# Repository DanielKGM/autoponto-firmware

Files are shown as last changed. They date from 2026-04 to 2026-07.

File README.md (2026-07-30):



[][doi-url]
[][contributors-url]
[][forks-url]
[][stars-url]
[][issues-url]
[][linkedin-url]

<!-- PROJECT LOGO -->
<br />
<div align="center">
  <a href="https://github.com/DanielKGM/autoponto-firmware">
    
  </a>

<h3 align="center">Chamadas Acadêmicas por Reconhecimento Facial</h3><br />
  <p align="center">
    <strong>AutoPonto</strong> é um sistema distribuído de computação de borda composto por três repositórios: código de <i>firmware</i>, aplicação <i>web</i> e servidor de borda. O objetivo é criar uma solução <b>barata</b> e <b>escalável</b> para automatização de chamadas acadêmicas através do reconhecimento facial, utilizando camadas independentes e conectadas por uma rede local. 
    <br /><br />
    <u>Este repositório</u> guarda o código-fonte do <i>firmware</i> dos dispositivos embarcados que são posicionados em salas de aula, responsáveis por coletar dados e interagir com usuários.
    <br />
    <br />
    <a href="https://github.com/DanielKGM/autoponto">Servidor Principal</a>
    &middot;
    <a href="https://github.com/DanielKGM/autoponto-edgenode">AutoPonto <i>EdgeNode</i></a>
    &middot;
    <a href="https://github.com/DanielKGM/autoponto-firmware/issues/new?labels=bug&template=bug-report---.md">Reportar Erro</a>
    &middot;
    <a href="https://github.com/DanielKGM/autoponto-firmware/issues/new?labels=enhancement&template=feature-request---.md">Sugerir Algo</a>
  </p>
</div>

<!-- TABLE OF CONTENTS -->
<details>
  <summary>Sumário</summary>
  <ol>
    <li><a href="#arquitetura-geral">Arquitetura Geral</a></li>
    <li><a href="#lista-de-materiais">Lista de Materiais</a></li>
    <li><a href="#esquema-elétrico-do-dispositivo">Esquema Elétrico do Dispositivo</a></li>
    <li><a href="#objetivos-específicos">Objetivos Específicos</a></li>
    <li><a href="#fluxo-de-execução">Fluxo de Execução</a></li>
    <li><a href="#estados-do-dispositivo">Estados do Dispositivo</a></li>
    <li><a href="#dependências-do-firmware">Dependências do <i>Firmware</i></a></li>
    <li><a href="#placa-de-circuito-impresso">Placa de Circuito Impresso</a></li>
    <li><a href="#caixa-de-montagem">Caixa de Montagem</a></li>
    <li><a href="#fotos-em-funcionamento">Fotos em Funcionamento</a></li>
    <li><a href="#configuração-local">Configuração Local</a></li>
    <li><a href="#mapa-de-arquivos">Mapa de Arquivos</a></li>
    <li><a href="#contexto-de-aula">Contexto de Aula</a></li>
    <li>
      <a href="#contrato-rest">Contrato <i>REST</i></a>
      <ul>
        <li><a href="#buscar-contexto">Buscar Contexto</a></li>
        <li><a href="#enviar-frame">Enviar <i>Frame</i></a></li>
      </ul>
    </li>
    <li>
      <a href="#contrato-mqtt">Contrato <i>MQTT</i></a>
      <ul>
        <li><a href="#status"><i>Status</i></a></li>
        <li><a href="#métricas">Métricas</a></li>
      </ul>
    </li>
    <li><a href="#contato">Contato</a></li>
    <li><a href="#licença-e-citação">Licença e Citação</a></li>
    <li><a href="#agradecimentos">Agradecimentos</a></li>
  </ol>
</details>

## Arquitetura Geral

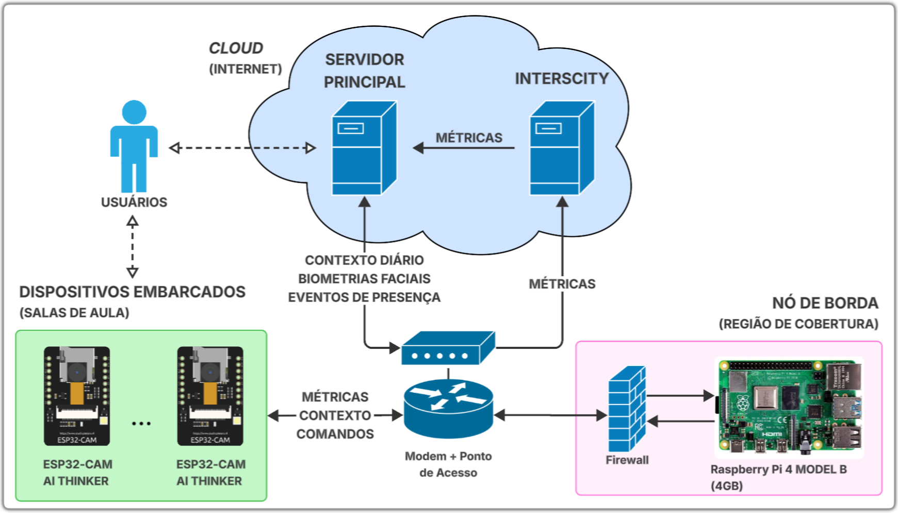
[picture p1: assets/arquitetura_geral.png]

<p align="justify">Quanta coisa é preciso para automatizar chamadas acadêmicas? Por exemplo, informações sobre o curso e rostos de alunos precisam ser cadastrados; então, em sala de aula, fotos precisam ser capturadas e capturas precisam ser processadas. Para atingir esses e (muitos) outros objetivos, o projeto utiliza uma arquitetura distribuída chamada <a href="https://www.intel.com/content/www/us/en/learn/what-is-edge-computing.html">computação de borda</a>. Isso permite diluir um monte de funcionalidades em camadas independentes, mas cooperativas:</p>
<ul>
<li><b>Dispositivos Embarcados</b> (este repositório): dispositivos eletrônicos posicionados em salas de aula. Eles são responsáveis por capturar fotos e exibir mensagens, portanto, interagem frequente e diretamente com os usuários;</li>
<li><b><a href="https://github.com/DanielKGM/autoponto-edgenode">Nó de Borda</a></b>: servidor intermediário implementado em <i>Raspberry Pi 4</i> ou outros <i>Single Board Computer</i> (<i>SBC</i>), seu propósito é fazer o reconhecimento facial, conectar os dispositivos embarcados com o servidor principal e armazenar uma parte <b>relevante</b> dos dados a cada sincronização (como rostos, aulas, alunos, matrículas, etc.);</li>
<li><b><a href="https://github.com/DanielKGM/autoponto">Servidor Principal</a></b>: regras de negócio, gerenciamento de usuários, persistência de dados, coleta biométrica, interface <i>web</i>, <i>dashboards</i>, relatórios, formulários <i>CRUD</i>, sincronização com nós, mapa <i>IoT</i>.</li>
<li><b><a href="https://github.com/DanielKGM/Playground_InterSCity">InterSCity</a></b> (opcional): trata-se de um <i>middleware IoT</i> feito por pesquisadores brasileiros da USP, onde métricas e <i>status</i> dos dispositivos podem ser publicados (pelos nós) e lidos (por aplicações). Não é necessário para o funcionamento do projeto, mas altamente recomendado como camada de <u>telemetria e monitoramento</u>.</li>
</ul>
<br/>
<p align="right">(<a href="#topo">voltar ao topo</a>)</p>

## Lista de Materiais

| Imagem | Componente <i>THT</i> | Especificação | Quantidade |
| :---: | :--- | :--- | :---: |
|  Fonte SAMSUNG | [Fonte de alimentação](<[URL_ALIEXPRESS_AQUI](https://www.mercadolivre.com.br/carregador-samsung-epta50bw-j6-j8-a6-plus-e5-de-15-ampere-fabricado-no-brasil/p/MLB19713348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)>) | Samsung EP-TA50BW, saída 5 Vcc e corrente máxima de 1,55 A | 1 |
| Conversor Bucker | [Conversor de tensão](https://pt.aliexpress.com/item/1005007653423578.html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) | MP1584, conversor <i>buck</i>, saída ajustada para 3,3 V | 1 |
| ESP32-CAM Devboard | [Microcontrolador com câmera](https://www.aliexpress.com/item/1005006967566203.html) | <i>ESP32-CAM</i> AI-Thinker | 1 |
| Display TFT redondo | [Módulo de <i>display</i>](https://pt.aliexpress.com/item/1005009766462228.html) | <i>TFT</i> circular 1,28'', controlador GC9A01, interface <i>SPI</i> | 1 |
| Sensor de presença | [Sensor de presença](https://pt.aliexpress.com/item/32946280844.html) | HC-SR602, sensor <i>PIR</i> de movimento | 1 |
| - | <i>Buzzer</i> ativo | TMB12A03, alimentação nominal de 3 V | 1 |
| - | Transistor <i>NPN</i> | S9013, usado no chaveamento do <i>display</i> e do indicador | 2 |
| - | Diodo <i>Schottky</i> | 1N5819, usado na proteção de alimentação e no circuito do IO4 | 2 |
| - | <i>LED</i> verde | Indicador visual de retorno positivo | 1 |
| - | <i>LED</i> azul | Indicador visual de alimentação | 1 |
| - | Resistor | 220 Ω | 1 |
| - | Resistor | 1 kΩ | 3 |
| - | Resistor | 4,7 kΩ | 1 |
| - | Resistor | 10 kΩ | 2 |
| - | Resistor | 20 kΩ | 1 |
| - | Capacitor cerâmico | 100 nF | 3 |
| - | Capacitor eletrolítico | 220 μF | 1 |
| Borne | Borne de entrada | KF128-MINI, 2 vias | 1 |
| Interruptor | [Interruptor gangorra](https://pt.aliexpress.com/item/1005009248936075.html) | KCD11, liga/desliga da alimentação | 1 |
| - | Chave tátil | 12D00G ou equivalente | 1 |
| - | [Placa de circuito impresso](https://jlcpcb.com/) | <i>PCB</i> do dispositivo embarcado | 5 |

<p align="right">(<a href="#topo">voltar ao topo</a>)</p>

## Esquema Elétrico do Dispositivo

A tabela abaixo separa o esquema elétrico total do dispositivo embarcado em diferentes partes, de acordo com a função de cada uma. Na prática, todas funcionam em conjunto em uma única placa de circuito impresso (<i>PCB</i>).

| Esquema Elétrico | Função no Dispositivo |
| :---: | :--- |
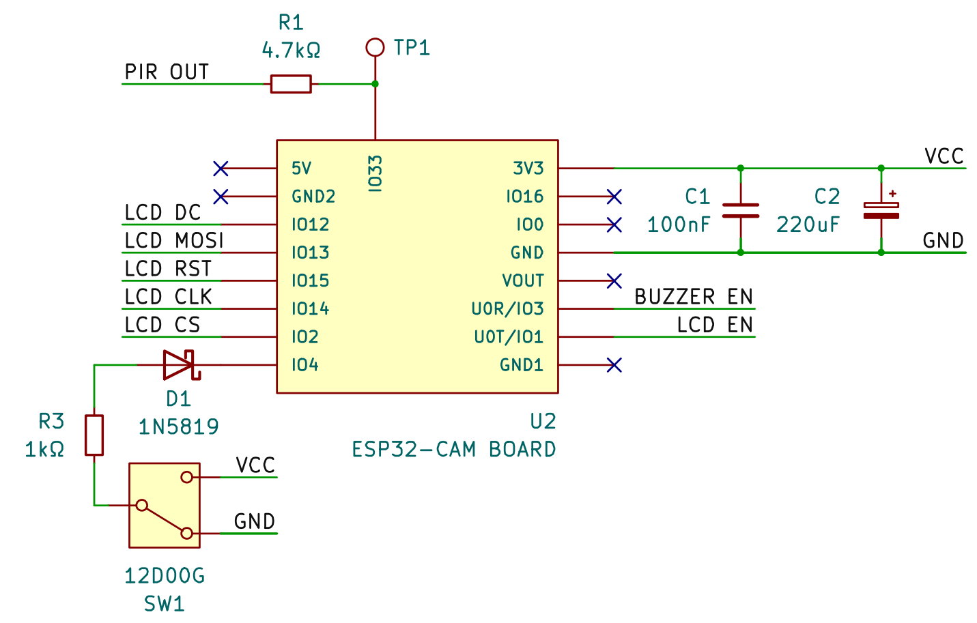
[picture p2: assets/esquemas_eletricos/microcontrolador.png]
Microcontrolador
| <br><sub>Microcontrolador</sub> | Atua como o "cérebro" do dispositivo. É responsável por executar o <i>firmware</i>, processar cálculos lógicos, receber dados dos sensores e enviar comandos para o <i>display</i> e indicadores. |
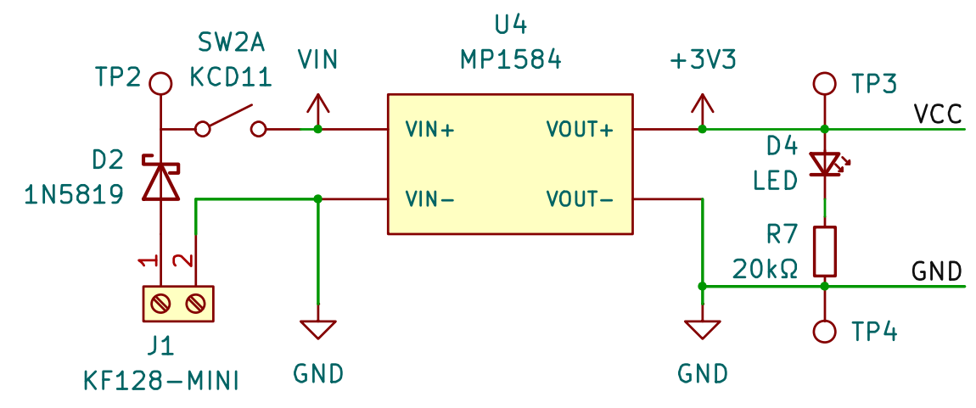
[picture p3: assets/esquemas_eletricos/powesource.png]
Fonte de Alimentação
| <br><sub>Fonte de Alimentação (<i>Power Source</i>)</sub> | Gerencia a energia do sistema. Recebe a energia externa e a converte/regula para 3.3V a fim de alimentar todos os componentes de forma segura e estável. |
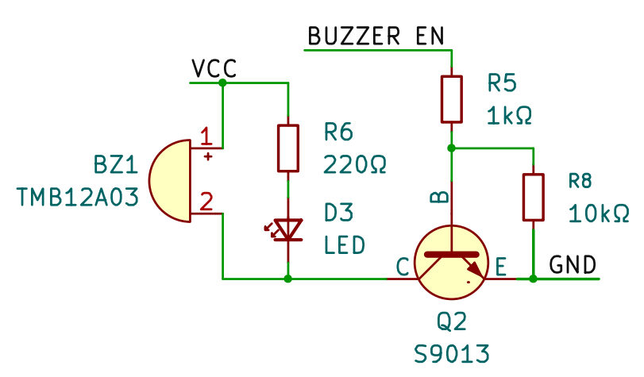
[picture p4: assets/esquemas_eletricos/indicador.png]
Indicador
| <br><sub>Indicador Visual (<i>Status</i>)</sub> | Fornece <i>feedback</i> visual e sonoro simples e rápido sobre o estado operacional do dispositivo. O <i>LED</i> verde é interpretado como um sinal positivo. |
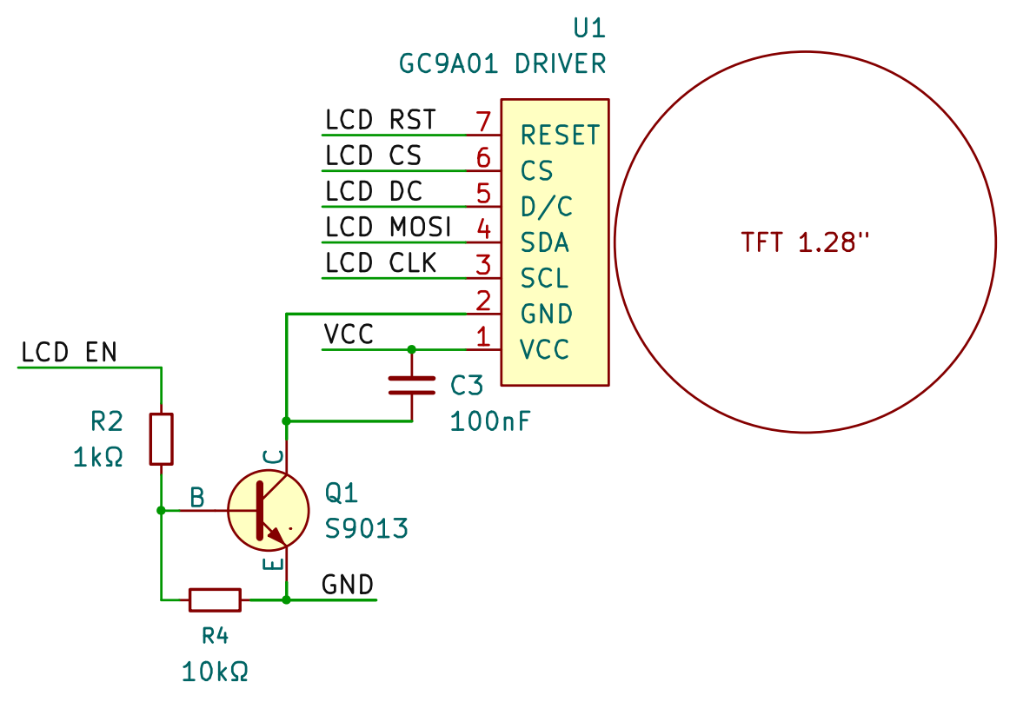
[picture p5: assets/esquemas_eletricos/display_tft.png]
Display TFT
| <br><sub><i>Display TFT</i></sub> | Interface gráfica do sistema. Utilizada para exibir informações mais detalhadas ao usuário e imagens da câmera em tempo real. |
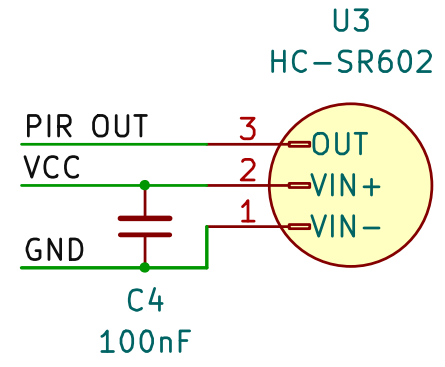
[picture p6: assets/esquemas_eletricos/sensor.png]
Sensor
| <br><sub><i>Sensor</i></sub> | Envia para o microcontrolador um sinal de usuário fisicamente presente/próximo ao dispositivo. Serve para ligá-lo ou retirar do modo de espera. |

<p align="right">(<a href="#topo">voltar ao topo</a>)</p>

## Objetivos Específicos

- Identificar o dispositivo pelo <i>MAC eFuse</i> do <i>ESP32</i>;
- Conectar ao <i>Wi-Fi</i> e ao <i>broker MQTT</i> configurados em <i>build time</i>;
- Buscar no <i>EdgeNode</i> o contexto de aula/chamada atual;
- Exibir <i>preview</i> da câmera ou mensagens de estado no <i>TFT</i>;
- Enviar <i>frames JPEG</i> periodicamente enquanto existe chamada ativa;
- Receber <i>feedback</i> de autenticação pelo <i>MQTT</i>;
- Publicar <i>status</i>, métricas de saúde e eventos de presença;
- Economizar energia quando não há movimento detectado pelo <i>PIR</i>.

<p align="right">(<a href="#topo">voltar ao topo</a>)</p>

## Fluxo de Execução

`src/main.cpp` é o ponto de entrada.

1. Desativa <i>brownout</i>, configura pinos e marca o estado `BOOTING`.
2. Gera `deviceId` a partir do <i>MAC eFuse</i> do <i>ESP32</i>.
3. Inicializa <i>TFT</i>, <i>sprites</i> de desenho, <i>sleep</i> e câmera.
4. Cria tarefas <i>FreeRTOS</i> para <i>display</i>, câmera, rede e <i>MQTT</i>.
5. No `loop()`, expira o contexto de aula, processa <i>PIR</i>, aciona <i>feedback</i> positivo,
   entra/sai de <i>idle</i> e dispara <i>deep sleep</i> quando aplicável.

As tarefas principais rodam em paralelo:

- `TaskDisplay`: desenha mensagens, <i>preview</i> da câmera e informações de contexto.
- `TaskCamera`: captura <i>frames</i> da câmera, alimenta <i>preview</i> e <i>snapshots REST</i>.
- `TaskNetwork`: conecta <i>Wi-Fi</i>, busca contexto <i>REST</i> e envia <i>frames JPEG</i>.
- `TaskMqtt`: conecta ao <i>broker</i>, assina comandos e publica <i>status</i>/métricas.

<p align="right">(<a href="#topo">voltar ao topo</a>)</p>

## Estados do Dispositivo

Os estados ficam em `include/Globals.h`:

- `BOOTING`: inicialização local.
- `NET_OFF`: <i>Wi-Fi</i> desconectado.
- `MQTT_OFF`: <i>Wi-Fi</i> ativo, <i>MQTT</i> desconectado.
- `FETCHING`: precisa buscar contexto de aula no <i>REST</i>.
- `WORKING`: contexto válido e operação normal.
- `WAITING_SERVER`: <i>frame</i> enviado, aguardando retorno pelo <i>MQTT</i> ou <i>timeout</i>.
- `SLEEPING`: preparando <i>deep sleep</i>.

`setState()` em `src/Globals.cpp` também publica <i>status MQTT</i> retido quando o
<i>broker</i> está conectado:

- `working`
- `fetching`
- `sleep`

A figura abaixo ilustra a máquina de estados do dispositivo embarcado:

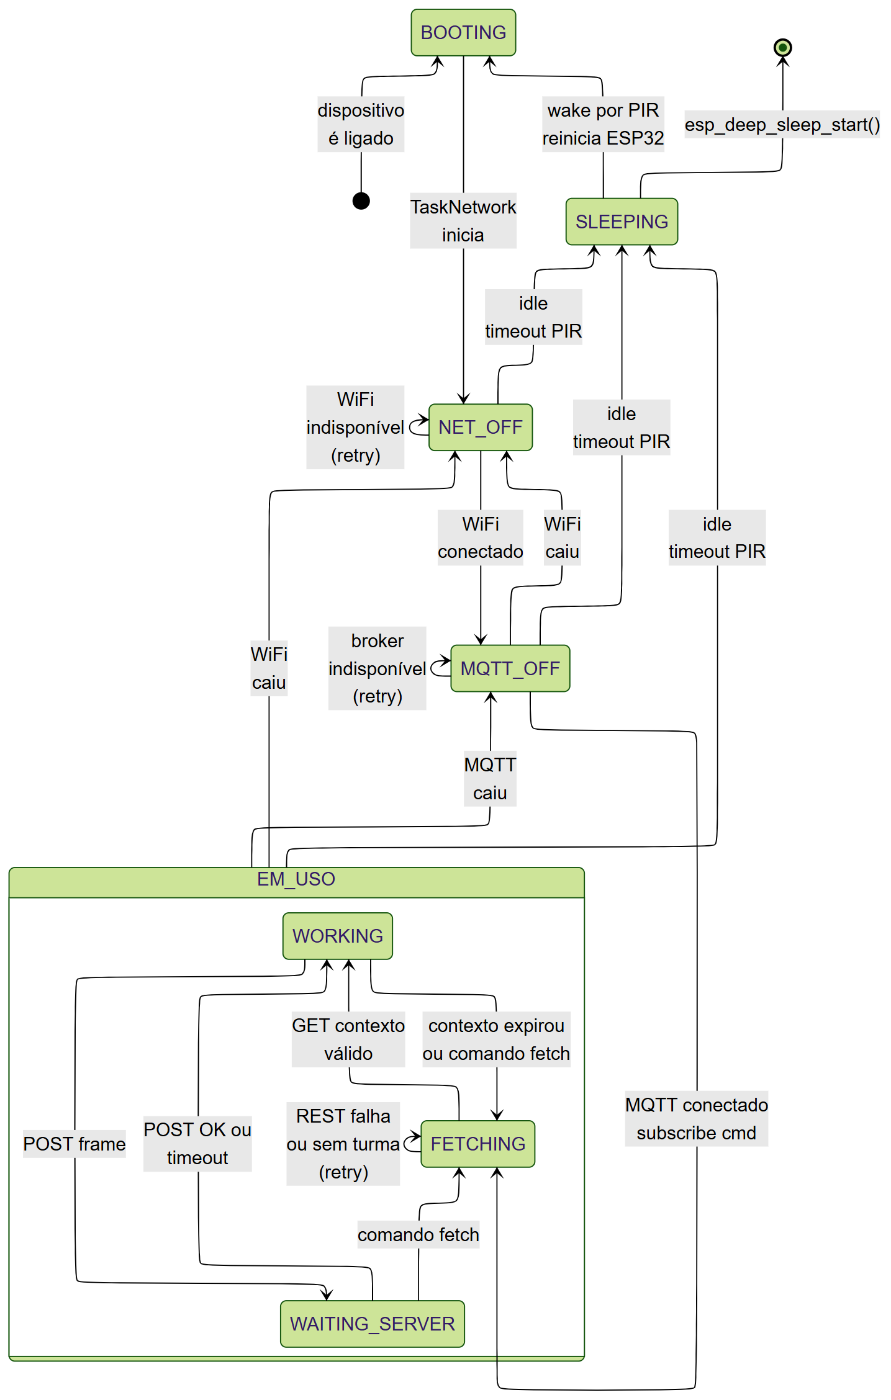
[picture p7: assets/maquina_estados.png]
Máquina de estados


<p align="right">(<a href="#topo">voltar ao topo</a>)</p>

## Dependências do <i>Firmware</i>

- <i>Framework</i>: Arduino sobre <i>ESP32</i> via <i>PlatformIO</i>
- Comunicação: <i>Wi-Fi</i>, <i>HTTP REST</i> e <i>MQTT</i>

| Dependência | Descrição |
| :--- | :--- |
| [bodmer/TFT_eSPI](https://github.com/Bodmer/TFT_eSPI) | Biblioteca gráfica e de fontes altamente otimizada para <i>displays TFT</i> baseados em <i>SPI</i>, focada em microcontroladores como <i>ESP8266</i>, <i>ESP32</i> e <i>RP2040</i>. |
| [bitbank2/JPEGDEC](https://github.com/bitbank2/JPEGDEC) | Decodificador <i>JPEG</i> otimizado para microcontroladores (escrito em C/C++), permitindo carregar e exibir imagens em <i>displays</i> com uso eficiente de memória. |
| [bblanchon/ArduinoJson](https://github.com/bblanchon/ArduinoJson) | Biblioteca de C++ eficiente e poderosa para serialização e desserialização de dados no formato <i>JSON</i>, muito utilizada em projetos Arduino e <i>IoT</i>. |
| [knolleary/PubSubClient](https://github.com/knolleary/pubsubclient) | Biblioteca para Arduino que fornece um cliente para o protocolo <i>MQTT</i> (<i>Message Queuing Telemetry Transport</i>), permitindo publicar e assinar tópicos para comunicação <i>IoT</i> em tempo real. |

<p align="right">(<a href="#topo">voltar ao topo</a>)</p>

## Placa de Circuito Impresso

Os circuitos eletrônicos do dispositivo são desenhados em uma placa de circuito impresso (PCB). Abaixo está o modelo 3D da PCB.

- [Clique neste LINK para visualizar em 3D](https://3dviewer.net/index.html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) &middot; [Arquivo Gerber](https://github.com/DanielKGM/autoponto-firmware/tree/main/assets/pcb)

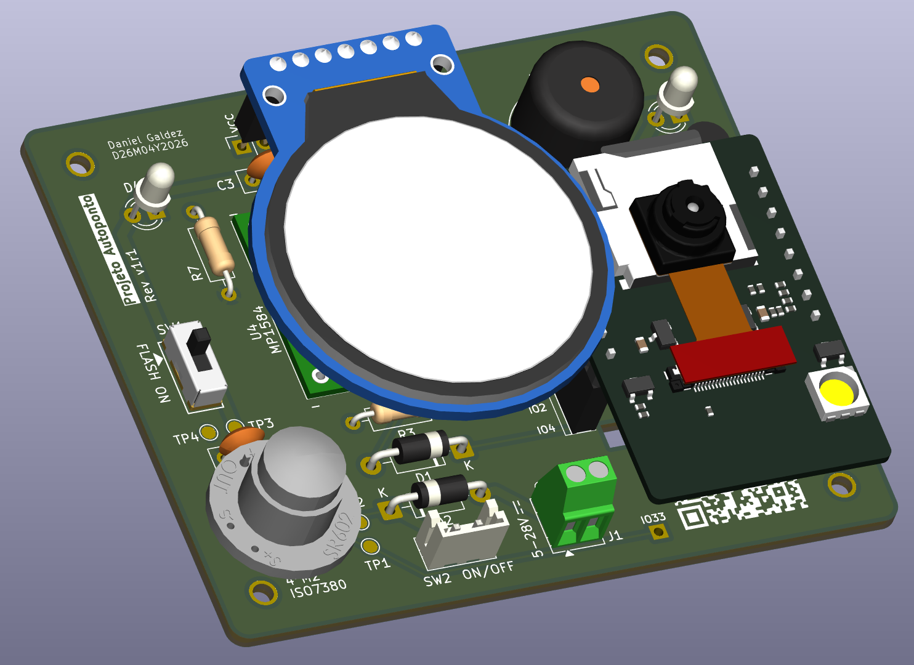
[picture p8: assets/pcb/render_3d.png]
Placa de Circuito Impresso


<p align="right">(<a href="#topo">voltar ao topo</a>)</p>

## Caixa de Montagem

Para testes em campo, os componentes eletrônicos e PCB precisam ser protegidos por uma caixa de montagem. A figura abaixo mostra o modelo 3D da caixa, que pode ser impresso em <i>PLA</i> ou outro material resistente.

- Clique nos LINKS a seguir para visualizar os arquivos de impressão: [BASE](https://3dviewer.net/index.html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) &middot; [TAMPA](https://3dviewer.net/index.html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) &middot; [TAMPA (SEM LOGO)](https://3dviewer.net/index.html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)

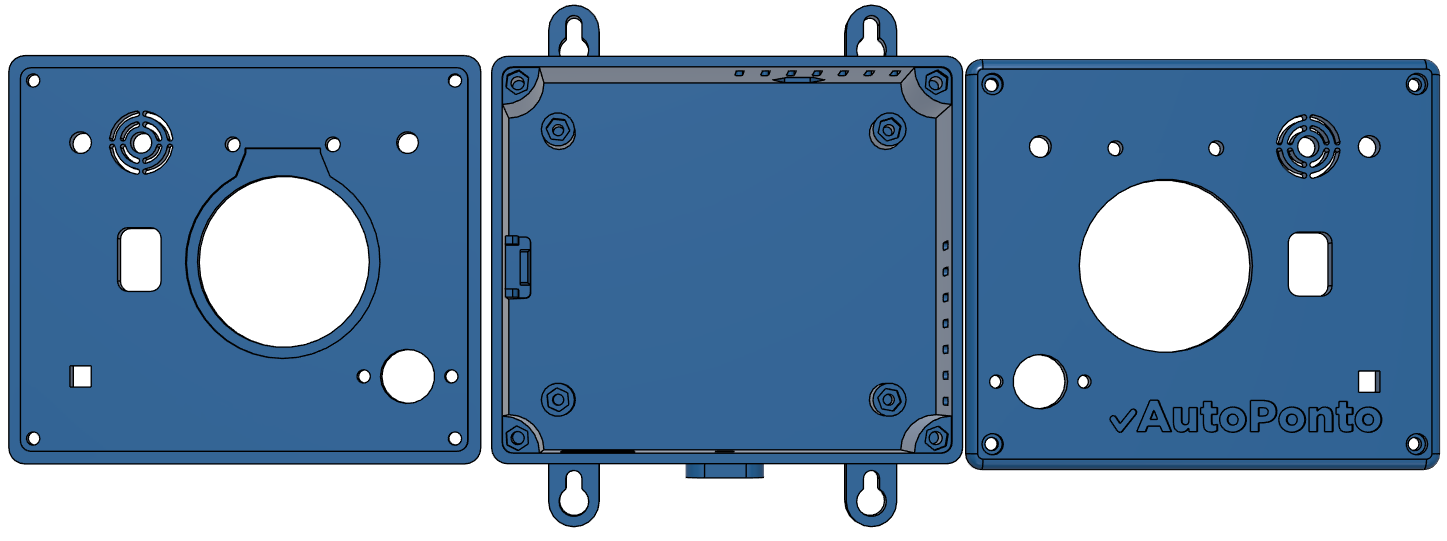
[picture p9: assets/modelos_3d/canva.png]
Caixa de Montagem


<p align="right">(<a href="#topo">voltar ao topo</a>)</p>

## Fotos em Funcionamento

| | |
| :---: | :---: |
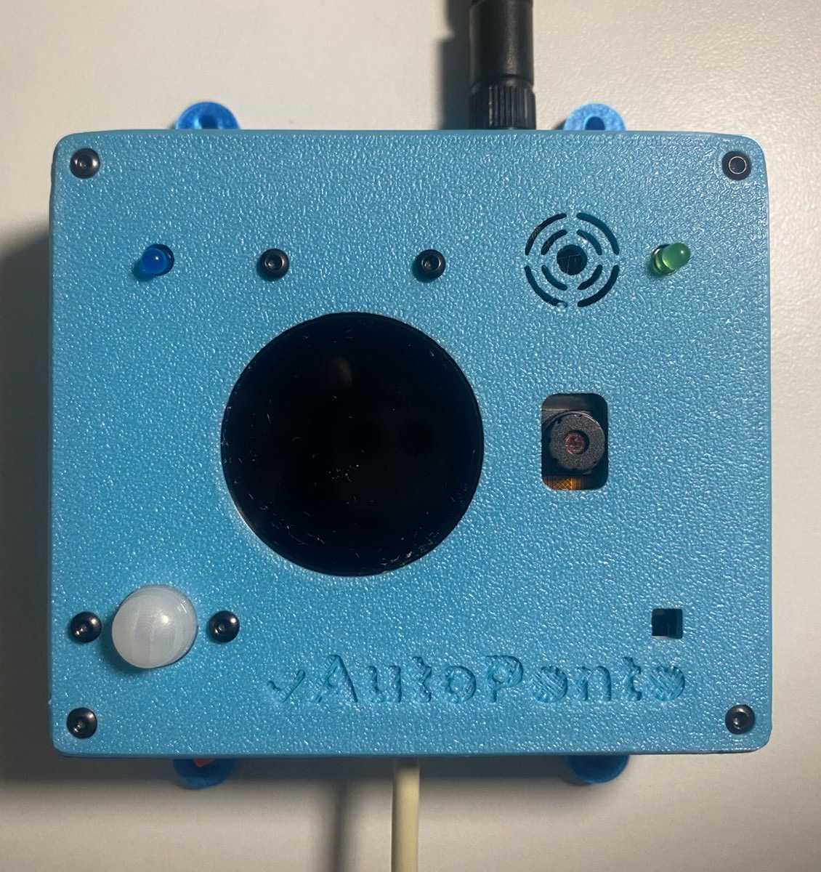
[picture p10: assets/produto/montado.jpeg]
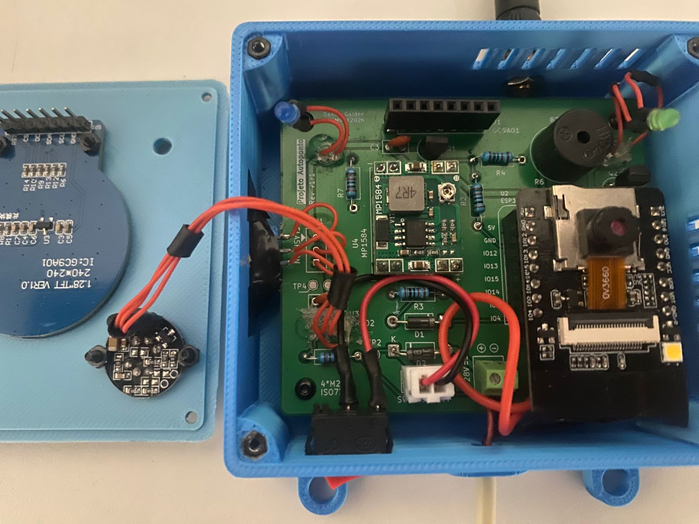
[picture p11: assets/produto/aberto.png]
| <br><sub>Dispositivo montado, não energizado</sub> | <br><sub>Por dentro do dispositivo embarcado</sub> |
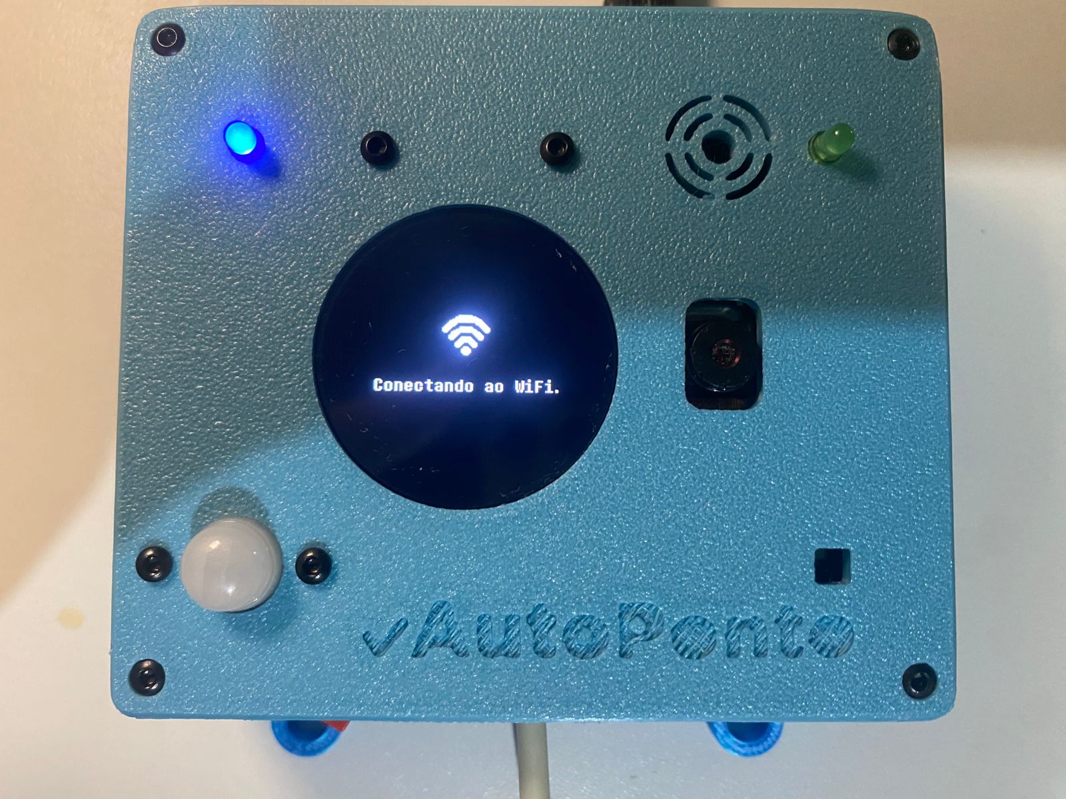
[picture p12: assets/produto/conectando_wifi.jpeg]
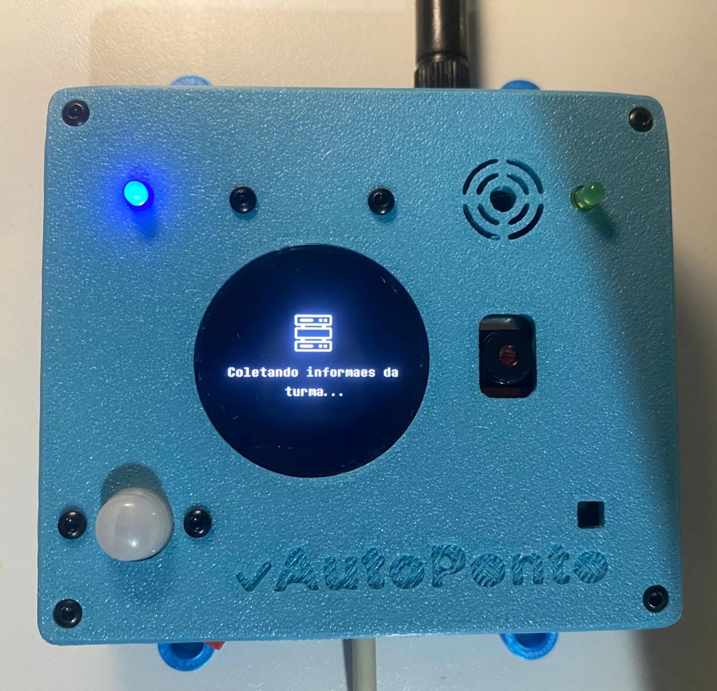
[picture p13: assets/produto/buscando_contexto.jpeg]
| <br><sub>Tentativa de conexão <i>Wi-Fi</i></sub> | <br><sub>Buscando contexto das aulas</sub> |
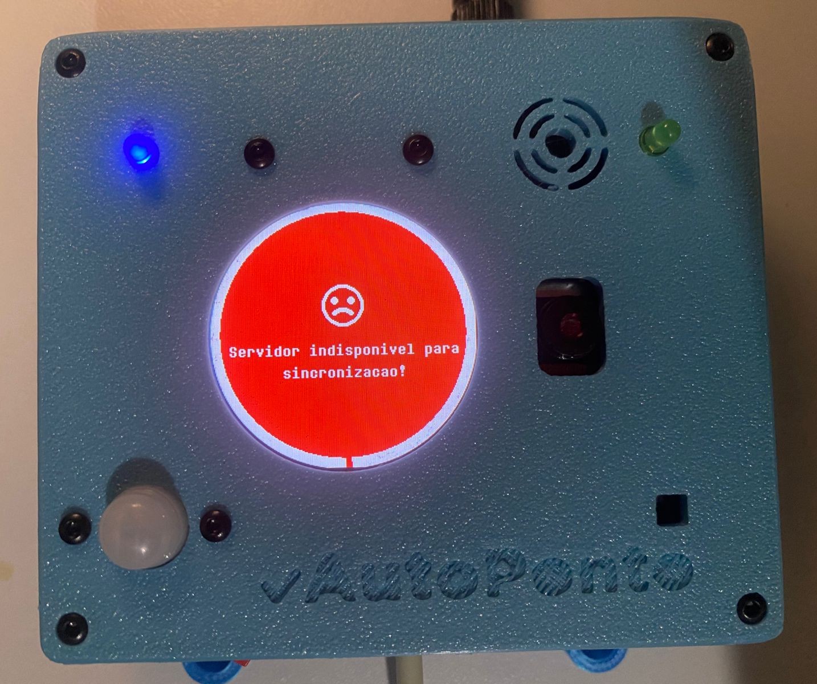
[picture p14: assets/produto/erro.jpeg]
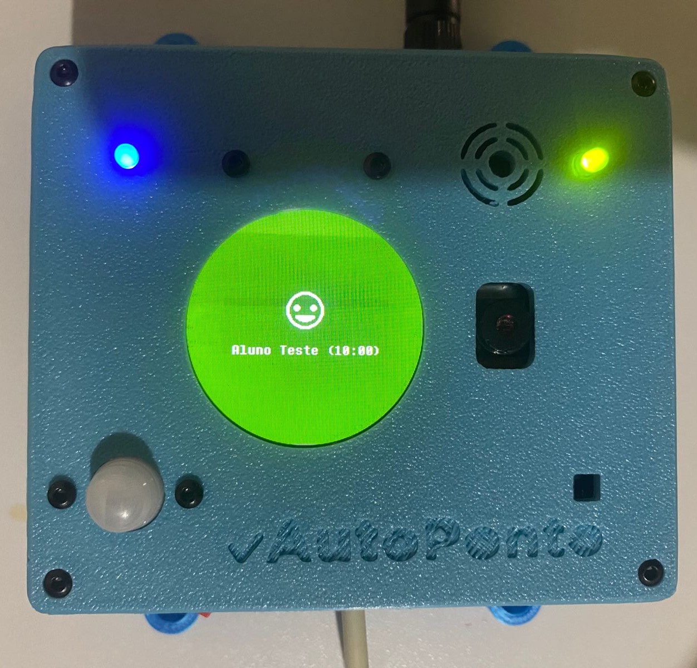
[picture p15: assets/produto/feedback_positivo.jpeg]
| <br><sub>Exibindo mensagem de erro</sub> | <br><sub>Exibindo <i>feedback</i> positivo após reconhecimento facial</sub> |
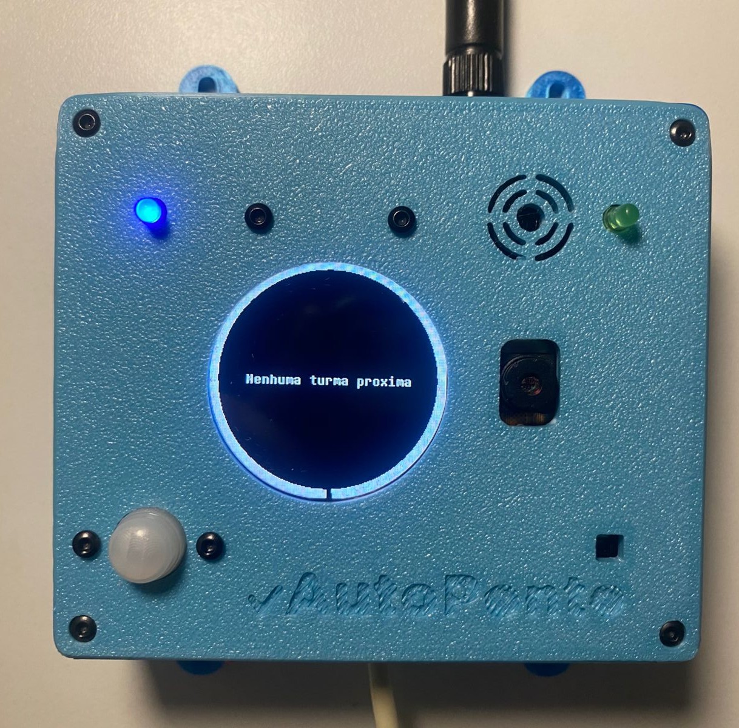
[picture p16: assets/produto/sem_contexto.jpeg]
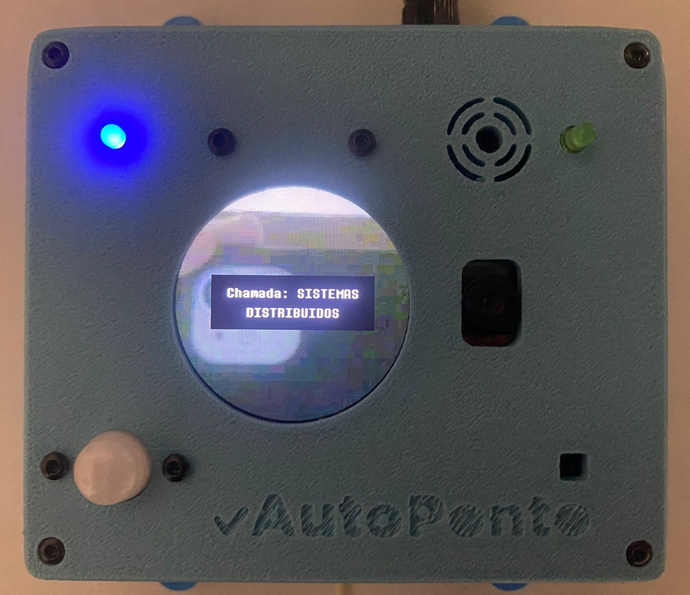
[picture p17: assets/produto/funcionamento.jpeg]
| <br><sub>Em funcionamento, mas sem turmas próximas</sub> | <br><sub>Em funcionamento normal: informações da turma e <i>feedback</i> da câmera</sub> |

<p align="right">(<a href="#topo">voltar ao topo</a>)</p>

## Configuração Local

O código inclui `Config.h`, mas esse arquivo não deve ser versionado. Ele fica
em `include/Config.h` e está ignorado pelo <i>Git</i> porque contém credenciais,
endereços e parâmetros de ambiente.

Para preparar um ambiente local:

```powershell
Copy-Item Config_Model.h include\Config.h
```

Depois edite `include/Config.h` com os valores reais:

- `WIFI_SSID` e `WIFI_PASS`
- `REST_URL`, `REST_PASS`, `REST_POST_PATH`, `REST_FETCH_PATH`
- `MQTT_URL`, `MQTT_PORT`, `MQTT_USER`, `MQTT_PASS`

`Config_Model.h` também documenta os parâmetros fixos de <i>build</i>, como pinos,
<i>timeouts</i>, intervalo de <i>POST REST</i>, intervalo de métricas <i>MQTT</i>, tamanho do <i>display</i>
e duração do <i>feedback</i> positivo. Não coloque credenciais reais no README nem em
arquivos versionados.

<p align="right">(<a href="#topo">voltar ao topo</a>)</p>

## Mapa de Arquivos

```text
.
|-- platformio.ini              Configuração PlatformIO, board, libs e build flags TFT
|-- Config_Model.h              Modelo de configuração local sem segredos
|-- README.md                   Este guia
|-- docs/
|   |-- FSM_DIAGRAM.mmd         Diagrama Mermaid da máquina de estados
|   `-- FSM_DIAGRAM.png         Render do diagrama
|-- include/
|   |-- Camera.h                API da câmera e FrameBuffer
|   |-- Config.h                Config local ignorada pelo Git
|   |-- Config_Camera.h         Pinos e parâmetros da câmera
|   |-- Display.h               API do display e ícones
|   |-- Font.h                  Fonte customizada usada no TFT
|   |-- Globals.h               Estados, contexto, tasks e métricas compartilhadas
|   |-- Icons.h                 Declarações dos ícones RGB565
|   |-- MQTT.h                  API MQTT, tópicos e limites de payload
|   |-- Network.h               API Wi-Fi/REST
|   `-- Power.h                 API de energia, PIR, idle e feedback
`-- src/
    |-- Camera.cpp              Inicialização/captura da câmera e filas de frame
    |-- Display.cpp             Renderização TFT, mensagens e preview
    |-- Globals.cpp             Estado global, contexto, métricas e helpers
    |-- Icons.cpp               Bitmaps RGB565 dos ícones
    |-- MQTT.cpp                Conexão MQTT, comandos, status e métricas
    |-- Network.cpp             Wi-Fi, fetch de contexto e POST de frames
    |-- Power.cpp               Pinos, PIR, idle, feedback e deep sleep
    `-- main.cpp                Bootstrap, criação das tasks e loop principal
```

<p align="right">(<a href="#topo">voltar ao topo</a>)</p>

## Contexto de Aula

O contexto compartilhado é `AttendanceContext`:

```cpp
struct AttendanceContext
{
    char lesson_name[LESSON_NAME_LENGTH];
    uint64_t msForNext;
    uint64_t msRemaining;
    TickType_t fetchTick;
};
```

Campos esperados do <i>endpoint REST</i> de contexto:

- `lesson_name`: nome da turma/aula.
- `msForNext`: tempo até a próxima chamada.
- `msRemaining`: tempo restante da chamada atual.

`fetchTick` é o instante local em que o contexto foi recebido. O <i>display</i>,
expiração no `loop()` e telemetria devem usar esse mesmo ponto de referência
para evitar divergência entre <i>UI</i>, validade do contexto e métricas.

Quando `msForNext == 0` e `msRemaining == 0`, o <i>firmware</i> trata como ausência de
turma próxima, limpa o contexto e segue tentando buscar novamente em intervalo
controlado.

<p align="right">(<a href="#topo">voltar ao topo</a>)</p>

## Contrato <i>REST</i>

`src/Network.cpp` concentra o tráfego <i>HTTP</i>.

### Buscar Contexto

Requisição:

- método: `GET`
- <i>URL</i>: `REST_URL + REST_FETCH_PATH`
- <i>headers</i>:
  - `X-Device-Id: <deviceId>`
  - `X-Auth: <REST_PASS>`

Resposta esperada:

```json
{
  "lesson_name": "Nome da turma",
  "msForNext": 0,
  "msRemaining": 300000
}
```

### Enviar <i>Frame</i>

Requisição:

- método: `POST`
- <i>URL</i>: `REST_URL + REST_POST_PATH`
- <i>body</i>: <i>JPEG</i> cru capturado pela câmera
- <i>headers</i>:
  - `Content-Type: image/jpeg`
  - `X-Device-Id: <deviceId>`
  - `X-Auth: <REST_PASS>`
  - `Connection: close`

O envio só acontece quando:

- o dispositivo está em `WORKING`;
- há chamada ativa (`context.msRemaining > 0`);
- o dispositivo não está em <i>idle</i>;
- não há mensagem <i>fullscreen</i> ativa no <i>display</i>.

Depois do <i>POST</i> bem-sucedido, o estado passa para `WAITING_SERVER`. Se não chegar
<i>feedback MQTT</i> dentro de `RESPONSE_WAIT_TIMEOUT_MS`, volta para `WORKING`.

<p align="right">(<a href="#topo">voltar ao topo</a>)</p>

## Contrato <i>MQTT</i>

`src/MQTT.cpp` concentra tópicos, conexão e <i>payloads</i>.

O `deviceId` tem 12 caracteres hexadecimais derivados do <i>MAC eFuse</i>. A partir
dele, os tópicos são:

- comandos: `cmd/{deviceId}`
- <i>logs</i>/<i>status</i>/telemetria: `log/{deviceId}`

### <i>Status</i>

O <i>firmware</i> publica <i>status</i> retido em `log/{deviceId}`:

```json
{ "kind": "status", "status": "working" }
```

O <i>Last Will and Testament</i> também usa `log/{deviceId}` com <i>payload</i> retido:

```json
{ "kind": "status", "status": "offline" }
```

<p align="right">(<a href="#topo">voltar ao topo</a>)</p>

### Métricas

A cada `MQTT_LOG_INTERVAL_MS`, publica `kind=metrics` sem <i>retain</i>:

```json
{
  "kind": "metrics",
  "idle": false,
  "heap_free": 0,
  "heap_min": 0,
  "heap_max": 0,
  "psram_free": 0,
  "psram_min": 0,
  "psram_max": 0,
  "rssi": 0,
  "post_max_ms": 0,
  "avg_us": {
    "loop": 0,
    "mqtt": 0,
    "network": 0,
    "camera": 0,
    "display": 0
  },
  "avg_count": {
    "loop": 0,
    "mqtt": 0,
    "network": 0,
    "camera": 0,
    "display": 0
  }
}
```

<p align="right">(<a href="#topo">voltar ao topo</a>)</p>

## Contato

[Daniel Galdez (LINKEDIN)](https://www.linkedin.com/in/daniel-campos-galdez-monteiro/) &middot; <a href="mailto:danielgaldez10@hotmail.com?subject=AUTOPONTO&body=Olá! Vim do repositório AUTOPONTO e ...">danielgaldez10@hotmail.com</a>

<p align="right">(<a href="#topo">voltar ao topo</a>)</p>

## Licença e Citação

<p align="justify">Este projeto é protegido por direitos autorais (<i>All Rights Reserved</i>). A cópia, distribuição, uso comercial ou modificação não são permitidas sem autorização prévia. Para mais informações, consulte o arquivo <b>LICENSE.md</b> ou a <b>aba de licença</b> do repositório.<br/><br/>Caso utilize este projeto em trabalhos acadêmicos ou científicos, utilize a seguinte referência BibTeX:</p>

```Latex
@software{AutoPonto_2026,
  author  = {Campos Galdez Monteiro, Daniel},
  month   = jul,
  title   = {{AutoPonto: Chamadas Acadêmicas por Reconhecimento Facial}},
  url     = {https://github.com/DanielKGM/autoponto-firmware},
  version = {1.0.0},
  year    = {2026}
}
```

<p align="right">(<a href="#topo">voltar ao topo</a>)</p>

<!-- ACKNOWLEDGMENTS -->

## Agradecimentos

<p align="justify">Agradeço a todos os professores do curso de Engenharia da Computação pela Universidade Federal do Maranhão (UFMA), pelos conhecimentos indispensáveis para realização desse projeto. Em especial, agradeço aos membros da minha bancada de TCC pela disponibilidade e paciência para avaliar este projeto com a nota máxima, e ao meu orientador Prof. Dr. Luis Henrique Neves Rodrigues.</p>

<p align="right">(<a href="#topo">voltar ao topo</a>)</p>

<!-- MARKDOWN LINKS & IMAGES -->
<!-- https://www.markdownguide.org/basic-syntax/#reference-style-links -->

[doi-shield]: https://img.shields.io/badge/DOI-10.5281/zenodo.21705236-black?style=for-the-badge
[doi-url]: https://doi.org/10.5281/zenodo.21705236
[contributors-shield]: https://img.shields.io/github/contributors/DanielKGM/autoponto-firmware.svg?style=for-the-badge
[contributors-url]: https://github.com/DanielKGM/autoponto-firmware/graphs/contributors
[forks-shield]: https://img.shields.io/github/forks/DanielKGM/autoponto-firmware.svg?style=for-the-badge
[forks-url]: https://github.com/DanielKGM/autoponto-firmware/network/members
[stars-shield]: https://img.shields.io/github/stars/DanielKGM/autoponto-firmware.svg?style=for-the-badge
[stars-url]: https://github.com/DanielKGM/autoponto-firmware/stargazers
[issues-shield]: https://img.shields.io/github/issues/DanielKGM/autoponto-firmware.svg?style=for-the-badge
[issues-url]: https://github.com/DanielKGM/autoponto-firmware/issues
[license-shield]: https://img.shields.io/github/license/DanielKGM/autoponto-firmware.svg?style=for-the-badge
[license-url]: https://github.com/DanielKGM/autoponto-firmware/blob/main/LICENSE.md
[linkedin-shield]: https://img.shields.io/badge/-LinkedIn-black.svg?style=for-the-badge&logo=linkedin&colorB=555
[linkedin-url]: https://www.linkedin.com/in/daniel-campos-galdez-monteiro/

<!-- BADGES TABELA-->

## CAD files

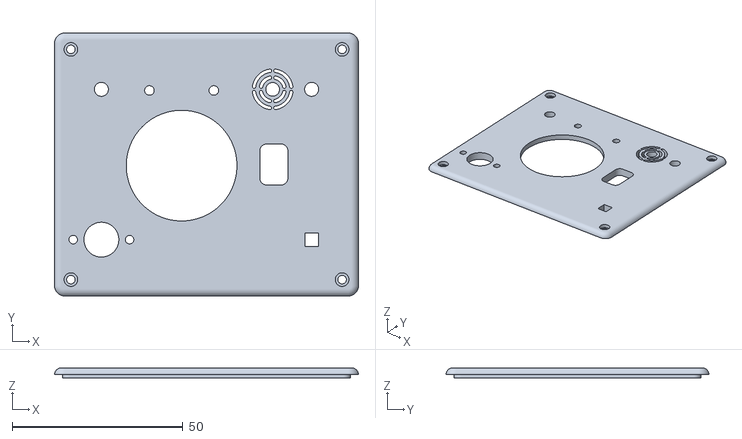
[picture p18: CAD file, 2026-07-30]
assets/modelos_3d/ap_tampa_semlogo.stl
89.0 x 77.0 x 3.00

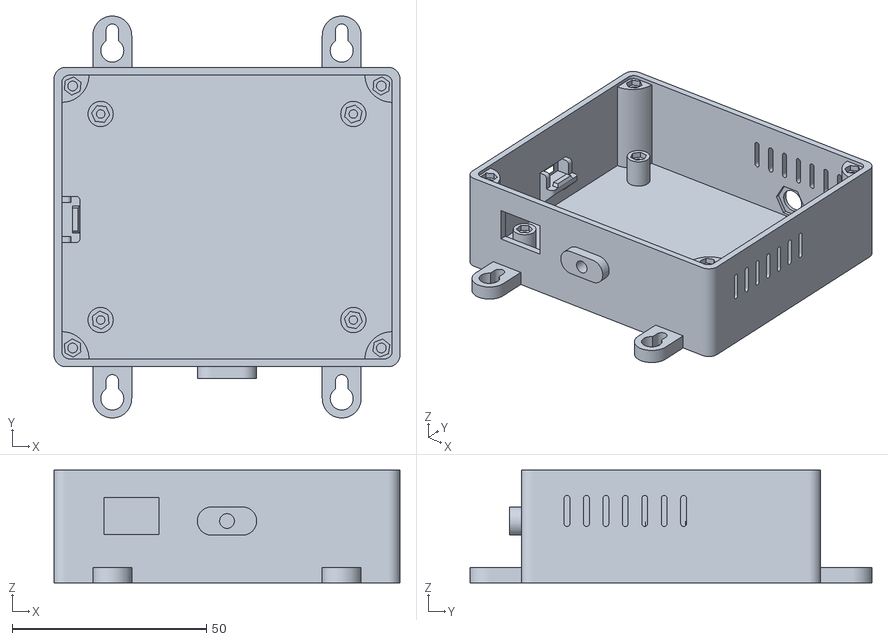
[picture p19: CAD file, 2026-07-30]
assets/modelos_3d/ap_base.stl
89.0 x 103.4 x 29.0

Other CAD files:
assets/modelos_3d/ap_tampa.stl

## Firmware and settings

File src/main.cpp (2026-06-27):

#include "Config.h"
#include "Globals.h"
#include "Power.h"
#include "Camera.h"
#include "Display.h"
#include "Network.h"
#include "MQTT.h"
#include "esp_timer.h"

const TickType_t ticksToSleep = pdMS_TO_TICKS(SLEEP_TIMEOUT_MS);
const TickType_t ticksToIdle = pdMS_TO_TICKS(IDLE_TIMEOUT_MS);
const TickType_t loopDelay = pdMS_TO_TICKS(99);
volatile TickType_t lastSensorTick = xTaskGetTickCount();

void loadID()
{
    uint64_t mac = ESP.getEfuseMac();

    snprintf(deviceId, sizeof(deviceId), "%04X%08X",
             (uint16_t)(mac >> 32),
             (uint32_t)mac);
}

void setup()
{
    WRITE_PERI_REG(RTC_CNTL_BROWN_OUT_REG, 0);

    power::configPins();
    setState(SystemState::BOOTING);

    loadID();

    display::configTFT();
    display::configSprite();

    xTaskCreatePinnedToCore(
        display::TaskDisplayCode,
        "TaskDisplay",
        16384,
        nullptr,
        2,
        &TaskDisplay,
        APP_CPU_NUM);

    power::configSleep();

    if (!camera::startCamera())
    {
        return;
    }

    xTaskCreatePinnedToCore(
        camera::TaskCameraCode,
        "TaskCamera",
        8192,
        nullptr,
        3,
        &TaskCamera,
        APP_CPU_NUM);

    xTaskCreatePinnedToCore(
        network::TaskNetworkCode,
        "TaskNetwork",
        16384,
        nullptr,
        2,
        &TaskNetwork,
        PRO_CPU_NUM);

    xTaskCreatePinnedToCore(
        mqtt::TaskMqttCode,
        "TaskMqtt",
        8192,
        nullptr,
        2,
        &TaskMqtt,
        PRO_CPU_NUM);
}

void loop()
{
    using namespace power;
    static TickType_t periodStartTick = xTaskGetTickCount();
    int64_t cycleStart = esp_timer_get_time();
    TickType_t now = xTaskGetTickCount();

    if (context.msRemaining > 0 &&
        getRemainingMs(now, context.msRemaining, context.fetchTick) == 0)
    {
        clearContext();
    }
    else if (context.msForNext > 0 &&
             getRemainingMs(now, context.msForNext, context.fetchTick) == 0)
    {
        clearContext();
    }

    if (sensorTriggered)
    {
        changeTriggeredFlag(false);
        lastSensorTick = now;
        mqtt::publish(mqtt::topicLogs, "{\"kind\":\"pir\",\"presenca\":true}", false);
        exitIdle();
    }

    if (buzzerTriggered)
    {
        buzzerTriggered = false;
        positiveFB();
    }

    if (!checkIdle() && (now - lastSensorTick) > ticksToIdle && !isBlockingIdle())
    {
        enterIdle();
    }

    if ((now - lastSensorTick) > ticksToSleep && checkIdle())
    {
        triggerSleepEvent();
    }

    recordTaskRuntime(TaskMetric::LOOP_TASK, static_cast<uint32_t>(esp_timer_get_time() - cycleStart));

    if (waitForNextPeriodOrSleep(periodStartTick, loopDelay) && checkTaskCount() == 0 && checkState(SystemState::SLEEPING))
    {
        sleep();
    }
}

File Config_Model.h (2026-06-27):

#pragma once

// ===== Valores fixos de build =====

//  Sensor de presença (PIR)
#define PIR_PIN 33
#define SLEEP_TIMEOUT_MS 300000 // Tempo sem detecção PIR para entrar em deep sleep (5 minutos)
#define IDLE_TIMEOUT_MS 60000   // Tempo sem atividade para entrar em modo de espera (1 minuto)

//  Configurações do display TFT
#define DISPLAY_ENABLE_PIN 1   // Pino para ativar/desativar transistor associado ao display
#define DISPLAY_WIDTH 240      // Largura do display em pixels
#define DISPLAY_HEIGHT 240     // Altura do display em pixels
#define DISPLAY_MSG_MAX_LEN 64 // Tamanho máximo da mensagem exibida no display

//  Feedback positivo
#define POSITIVE_FB_PIN 3 // Liga o buzzer ativo e o LED indicador
#define POSITIVE_FB_DURATION_MS 1000

//      WiFi
#define WIFI_TIMEOUT_MS 10000

//      Servidor REST
#define REST_TIMEOUT_MS 8000
#define REST_POST_INTERVAL_MS 3000 // Intervalo entre envios de frames em milissegundos

//      Servidor REST + MQTT
#define RESPONSE_WAIT_TIMEOUT_MS 5000 // Tempo de espera, por MQTT, de uma resposta após POST REST
#define MQTT_LOG_INTERVAL_MS 30000

// ===== Credenciais e endpoints fixos de build =====

//      WiFi
#define WIFI_SSID ""
#define WIFI_PASS ""

//      Servidor REST
#define REST_URL ""
#define REST_PASS ""
#define REST_POST_PATH ""
#define REST_FETCH_PATH ""

//      Servidor MQTT
#define MQTT_URL ""
#define MQTT_PORT 0
#define MQTT_USER ""
#define MQTT_PASS ""

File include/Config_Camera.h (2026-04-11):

#define RESET_GPIO_NUM -1
#define XCLK_GPIO_NUM 0
#define XCLK_FREQ_HZ 20000000
#define SIOD_GPIO_NUM 26
#define SIOC_GPIO_NUM 27
#define Y9_GPIO_NUM 35
#define Y8_GPIO_NUM 34
#define Y7_GPIO_NUM 39
#define Y6_GPIO_NUM 36
#define Y5_GPIO_NUM 21
#define Y4_GPIO_NUM 19
#define Y3_GPIO_NUM 18
#define Y2_GPIO_NUM 5
#define VSYNC_GPIO_NUM 25
#define HREF_GPIO_NUM 23
#define PCLK_GPIO_NUM 22
#define BUFFER_NUMBER 2
#define JPEG_QUALITY 10

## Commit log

2025-12-16 feat: adicionado o feedback em tempo da câmera para o display GC9A01
2025-12-17 chore: config. da ESP32 CAM para serial monitor do PlatformIO
2025-12-19 feat: freeRTO friendly task do Display, refactor: código refatorado para boas práticas e legibilidade, build: definição de configurações do TFT_eSPI no build do platformio
2025-12-19 feat: multiprocessamento entre tasks NETWORK e DISPLAY, feat: capacidade de enviar e imprimir mensagens na task display
2025-12-19 fix: erro de lógica na contagem de ticks sem PIR até o deep sleep
    [main.cpp]
2025-12-19 feat: estrutura de conexão com rede e servidor tcp
2025-12-20 feactor: erros de exibição no display
2025-12-20 revert: conexão com servidor "desimplementada" para recomeçar
    [main.cpp]
2025-12-20 fix: câmera não iniciando, feat: conexão ao WiFi
    [Camera.cpp, Display.cpp]
2025-12-21 fix: correção na exibição de texto de network
    [Display.cpp]
2025-12-21 refactor: captura do driver em JPEG, feat: renderização de buffer da câmera no display por decodificação JPEG
2025-12-21 feat: servidor tcp de teste flask
2025-12-22 chore: mudança de local de declaração de variáveis
2025-12-23 feat: comunicação MQTT com broker privado
    [Config_Model.h, Display.cpp]
2025-12-23 removida pasta que não deveria estar no repositório
2025-12-23 feat: task de mqtt
2025-12-23 feat: lógica de conexão MQTT-WIFI
2025-12-23 feat: publicação de mensagens MQTT, feat: recebimento de comandos MQTT
2025-12-23 fix: declaração incorreta de variáveis
    [main.cpp]
2025-12-23 fix: erro de lógica na conexão
2025-12-23 feat: logs periodicos de memória e sinal
2025-12-23 feat: POST periódico de frames por HTTP, chore: reorganização dos cabeçalhos
2025-12-24 feat: adicionados ícones para mensagens do display, feat: adicionada rotação correta do feedback da câmera, relacionado ao design, fix: corrigida lógica de reconnect mqqt após desconexão, chore: mode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
    [Camera.cpp, Config_Model.h, Display.cpp]
2025-12-24 fix: logica de reconnect mqtt
    [Display.cpp]
2025-12-25 fix: consertada lógica de exibição do display
    [Display.cpp]
2025-12-26 fix: inicializada a fila de eventos
    [Display.cpp, main.cpp]
2025-12-26 feat: texto estilo diálogos de undertale
2025-12-27 feat: mensagens com quebra de linha e elipse, refactor: corrigido o fluxo de estado (baseado em gráfico de petri)
    [Display.cpp, Power.cpp, main.cpp]
2025-12-27 minor: alteração na mensagem log de status
2025-12-27 fix: lógica de entrar no idle fiel ao gráfico de petri, apenas entra em IDLE no estado working
    [main.cpp]
2025-12-27 feature: cores de fundo para dialogos com ícones
2025-12-27 minor: corrigida lógica de postagem do status idle
    [main.cpp]
2025-12-28 feat: spinner para mensagens temporarizadas
2025-12-28 refactor: movida idleFlag para modulo POWER
2025-12-28 refactor: movido idleFlag para modulo POWER
2025-12-29 minor: removida duplicação de lógica na publicação de logs
2025-12-30 feat: fetch de informações sobre turmas
2025-12-30 refactor: movido trigger sleep para modulo power
2025-12-30 feat: sincronização de dados com o servidor
2025-12-31 fix: erro de lógica ao fazer requisições e exibir imagens ao mesmo tempo (tela como travamentos)
    [Display.cpp, Power.cpp, main.cpp]
2026-01-06 minor: corrigido erro em inicializar o display duas vezes
    [Display.cpp]
2026-01-06 minor: removidas publicações desnecessárias de status via MQTT
2026-04-04 fix: removido log interval (implementado por comando)
    [Config_Model.h]
2026-04-04 fix: lógica de boot do runtime config
2026-04-04 feat: ícone de bluetooth
2026-04-04 feat: modo configuração por bluetooth, feat: recebimento de comandos por bluetooth
2026-04-05 chore: flags de build para otimização de espaço
2026-04-05 fix: consertado ativamento do modo configuração
    [Power.cpp, main.cpp]
2026-04-05 refactor: tornar nomes de algumas variáveis mais autoexplicativos
2026-04-11 Refactor state checks and improve message handling in MQTT and Network modules
    - Added state check for WAITING_SERVER before processing auth in MQTT.cpp.
    - Updated display message to use "message" field instead of "student" in MQTT.cpp.
    - Simplified HTTP response handling in Network.cpp by introducing a boolean variable for clarity.
    - Enhanced error handling for server availability in Network.cpp.
    - Prevented redundant state setting in Power.cpp by checking if already in FETCHING state before proceeding.
    - Changed state to WORKING in Power.cpp when starting a new operation.
    [Power.cpp]
2026-04-11 refactor: update REST request handling by removing device ID from fetch path
2026-04-11 refactor: reorganize camera module and introduce frame buffer management
2026-04-11 refactor: adjust JPEG quality and MQTT payload size, improve error message display duration
    [Config_Camera.h]
2026-05-31 Refactor configuration handling and remove Bluetooth support
    - Removed Bluetooth icon and related code from Display and Icons.
    - Replaced RuntimeConfig with Config in MQTT and Network modules.
    - Updated MQTT and Network to use constants for configuration values.
    - Removed RuntimeConfig.cpp and its associated functionality.
    - Simplified device ID loading in main.cpp and removed unnecessary preferences handling.
    - Cleaned up power management code by removing unused configuration state.
    [Config_Model.h, Display.cpp]
2026-06-02 refactor: update camera initialization to enable vertical flip, adjust display messages for context clarity, and improve network handling logic
    [Camera.cpp, Display.cpp]
2026-06-02 refactor: remove vertical flip setting from camera initialization
    [Camera.cpp]
2026-06-02 refactor: replace TickType_t with uint64_t for timing in AttendanceContext and related functions
    [Display.cpp, main.cpp]
2026-06-28 docs: update flowcharts and README to enhance firmware architecture overview and task descriptions
2026-07-30 chore: Add 3d files and render images
    [ap_base.stl, ap_tampa.stl, ap_tampa_semlogo.stl]
2026-07-30 docs: update README with PCB and mounting box sections; remove outdated render image
2026-07-30 Remove 'voltar ao topo' links from README
    Removed 'voltar ao topo' links from the README.
